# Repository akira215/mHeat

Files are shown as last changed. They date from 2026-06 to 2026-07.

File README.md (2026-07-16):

# mHeat
Monitoring HomeBus device and Modbus, embedded sofware on dedicated PCB using ESP32C6 µC

# Description

This repository contain all the development for an electronic device that will monitor a water tank (such as rain collect tank) using zigbee to transmit data to a coordinator. It contains: 
 * A PCB design [PCB design](PCB/README.md)
 * An enclosure design to be printed in 3D [Enclosure design](3Dprint/README.md)
 * Source code of the embedded software on the board (in an ESP32C6 µC)
 * An External converter for Zigbee2MQTT service [external converter](external_converters)

# Principle

The board will collect data from various sensors surch as:
 * Upstream static pressure (pump side)
 * Downstream static pressure (home side) - difference between upstream and downstream static pressure is used to estimate filters clogging
 * Water level sensor, to estimate the available water volume in the tank
 * water pulse meter to count the consumption in the home
 * Additionally on board temperature sensor could be monitor

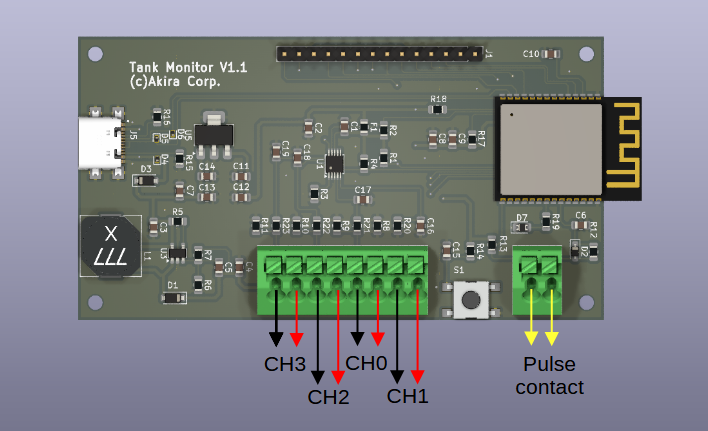
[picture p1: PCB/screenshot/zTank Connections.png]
zTank connections
 

 The 3 first sensors shall be 4-20mA sensor directly connected to the board. The water counter shall be a dry contact meter, connected to the board

 All these sensors have a calibration factor that can be updated directly form Zigbee2MQTT GUI. To avoid losing calibration, the device itself will keep updated theses factor in its Non Volatile Storage.

z2m settings (specific)

A 4-20mA input is available for any other futher sensor requirement. Adding a sensor will require to :
 * Update the embedded software
 * Update the external converter on Zigbee2MQTT side

## Usage

  * Short press button to join the zigbee network (coordinator shall grant pairing) -> LED shall flash, until network is joined, it then shutoff
  * Long press button to leave network. When the LED is fixed on, the device is not connected to the network neither is trying to join

## Sensor selection

### Upstream and downstream static pressure

  Regular pressure transmitter are not so expensive and efficient for that purpose. These 2 sensors shall have a measured range according to installation pressure. In regular network, pressure is limited to 3 bars, so selecting a sensor 0-5 bars seems a good choice. If the upper value is higher, the resolution of the measurement will be less as the ADC converter resolution is fixed.

  The shunt to convert current to tension for the ADC converter is 133R, and Imax for the sensor @max range will be 20mA so Umax for ADS1115 will be 2.66V (U=R*I). 5 bars = 500 kPa, so the calibration factor shall be 500 kPa / 2.66V = 187.97 kPa/V. Of course this factor shall be adjusted by measuring at the same location of one sensor the pressure, and correcting the reading of the sensor, but this short computation can help to start setting up calibration factor

### Water level

  Whatever technology of sensor could be used as soon as its output is 4-20mA current. Tests have been done using submerged differential pressure sensor, with the balance pipe to get the atmospheric pressure that run with the electrical cable, they worked properly. The range of this sensor shall be in accordance with the depth of the tank. The output value of Zigbee2MQTT will be a % of depth (meaning 100% when tank is full). Depending on the shape and cross section of the tank, this could be converted to a volume directly in the Z2M external converter, or outside Z2M in another software.

  The shunt to convert current to tension for the ADC converter is 133R, and Imax for the sensor @max range will be 20mA so Umax for ADS1115 will be 2.66V (U=R*I). For 100% the calibration factor shall be 100% / 2.66V = 37.594 %/V. 
  
  Of course this factor shall be adjusted when tank is full to read 100% in the Zigbee2MQTT output. For example, if yo have a 0-2m sensor and the require stroke of your tank (max height - min height before depriming pump) is 1.5m, it means that the 100% value of your tank will occur when sensor will read 1.5m (take care to install the sensor just before depriming pump). The voltage at the converter will be 1.5m/2m * 2.66V = 1.995V, so you will have to set the calibration factor considering 100% / 1.995V = 50.125%/V

### Water pulse counter

  The water meter shall send a pulse each XX L, whatever XX is. It is expected to have a dry contact that switch on and off each pulse. Hardware debouncer has been implemented for a particular counter, measuring bouncing using an oscilloscope. Computation of this RC filter has been provided here:
  [Spreadsheet](<PCB/2024-06-29 Comput.ods>)
    
  The kFactor to be set up in Zigbee2MQTT is only the L per pulse of the counter.

## Zigbee2MQTT integration

### External converter

External converter shall be loaded according to Zigbee2MQTT instructions:

[Zigbee2MQTT external converters](https://www.zigbee2mqtt.io/advanced/more/external_converters.html)

Restart Zigbee2MQTT `Webpage > Settings > Tools > Restart Zigbee2MQTT`

### Pairing zTank device

If the LED is fixed on, short press one time on the button, this will put the device in pairing mode.
Device is in Pairing Mode when the LED flahes quickly. 

Put Coordinator (or other device) in pairing mode using Zigbee2MQTT GUI (antenna symbol on the upper right of the screen with mention `All`)

After a short time, LED shall stop flashing. When LED is off, device is paired. You can check on Zigbee2MQTT device list

### Device icon

To add an icon in Zigbee2MQTT GUI, create a folder named `device_icon` in the root of Zigbee2MQTT docker installation (folder containing `configuration.yml`). In that foler, put the `zTank_icon.png` file contained in the `img` directory of this repository.

On Zigbee2MQTT GUI, go to `Devices` list and click on the device. Go to `Settings` tab and scroll down to the `icon` box.
Put `device_icons/zTank_icon.png` in that box. Icon shall be visible on Zigbee2MQTT GUI.

### Reporting

To develop*******************************************************************

## Build Instructions

The embedded software required `esp-ash-components`:

```
git submodule add https://github.com/akira215/esp-ash-components.git components
```

Create a partition.csv for zigbee and configure menuconfig with custom partition table (shall be done by default)

## Configuration

Configuration is available in `menuconfig` in the `Project setting` section:

### Pin Layout

  This section refer to hardware connection of LED button and volume meter. <span style="color:red">**These settings shall not be changed unless new hardware is developped.**</span>

pin layout

### Zigbee endpoints

  This section refer to the endpoint for each sensor of the device. Any change in this number require to update the external converter accordingly

Zigbee endpoints

  And in Zigbee2MQTT external converter:

External converter

### Zigbee device

  Zigbee stack has been sized doing extensive tests. <span style="color:red">**This setting shall not be changed.**</span>

Zigbee device

### ADS Pin Layout

  This section refer to hardware connection of ADS1115 converter to µC pin. <span style="color:red">**These settings shall not be changed unless new hardware is developped.**</span>

ADS pin layout

### ADS Converter config

  The first 3 inputs refer to the channel in which each sensor is connected. Take care that channel are not implemented on the connector in a logical order, so please refer to pictures that describe which pins of the connector is connected to which ADC channel (and polarity for sensors)

  The delay between 2 queries of ADS is the update rate of the measurement. Between 2 measurement, ADS is put in sleep to optimize consumption. Take care that driver will trigger one conversion for each channel, so there is a minimal time between 2 queries, depending on the resolution set for the ADS.

  The delay between 2 queries of temperature is the update rate of the measurement of the internal µC temperature sensor.

ADS converter config

## Current Status

Still work in progress, but is completely running. All bugs 
could be reported to try to improve it.

## PCB design

[PCB design](PCB/README.md)

## Enclosure design design

[Enclosure design](3Dprint/README.md)

## Caveats

### To be developped

OTA update

## Usage and Examples

## Changes

### New in version 0.0.0

## Credits

 * [Zigbee2MQTT](https://github.com/Koenkk/zigbee2mqtt)

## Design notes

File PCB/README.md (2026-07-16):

# zHeat PCB
A dedicated PCB using ESP32C6 µC as been designed to optimize reliability and costs.

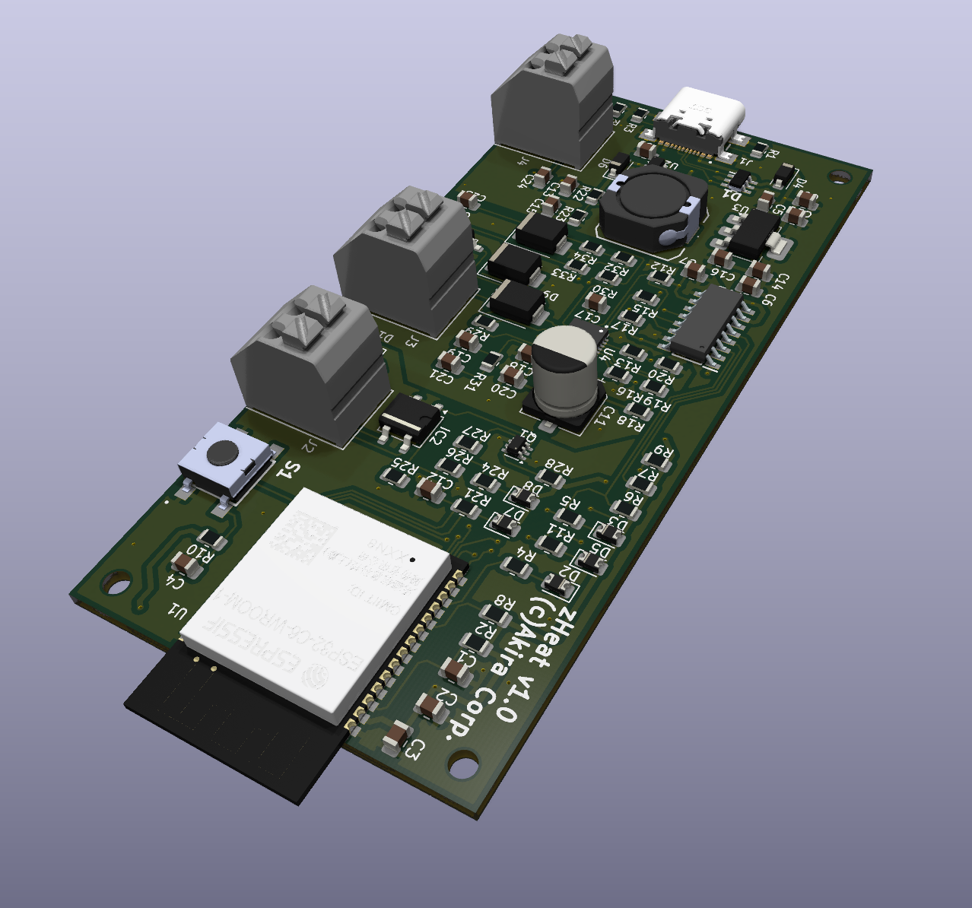
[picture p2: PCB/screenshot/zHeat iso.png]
Iso view of zTank PCB


The board connect to:

* Homebus to connect Daikin Heat Pump via P1P2 connector

* 12V serial bus to connect on heating circuit controller

* 4-20mA port to connect to pressure sensor on the circuit

## Tools

 The design of the PCB has been done with KiCad 10.0. Particular footprint and 3D STEP file are included in the `/library` folder for sake of maintenance

## Design

 The design is based on ESP32C6 WROOM with the following peripherials:
 * USB for power, flash device and output serial debug / info.
 * Powering circuit is done using MCP1826S 
 * A 4-20mA loop is built based on a LM2735X (1.6MHz) to raise voltage to about 20V
 * 4 channels 4-20mA sensors is provided and converted using ADS1115IDGS. It communicate with µC with i2c port
 * a debounced contact is provided for pulse counter
 * A push button is also provided for very simple HMI
 * PCB is also equipped by a LED for simpl HMI
 * Finally PCB is equipped with header that can be used for a touchscreen device in case of future needs (software lib already written and tested)

 Component size has been selected to 0805, except ESD protective diodes that are smaller.

### USB

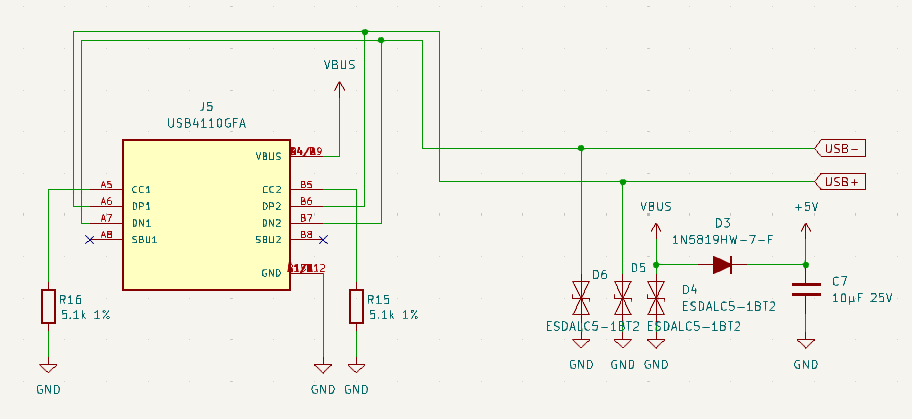
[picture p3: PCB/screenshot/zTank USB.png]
USB schematic
  

  USB socket is grounded to the main ground planes (2 sides).
  USB Lines `USB-` and `USB+` are directly connected to ESP32C6 to flash and monitor µC.
  `VBUS` is used to provide `+5V` (which is in fact lower than +5V) via a protective diode `D3`.

  All this 3 lines are protected by ESD protective diode.

### Voltage regulator

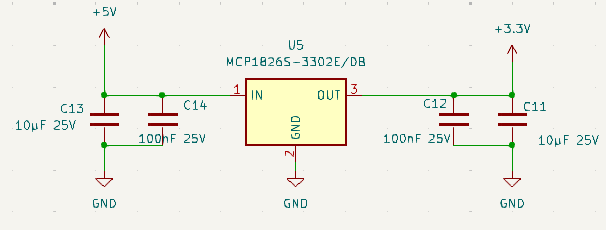
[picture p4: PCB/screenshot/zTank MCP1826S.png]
Regulator schematic
  

  All the board is powered using `+3.3V`. This voltage is provided by a fixed low-voltage regulator MCP1826S-3302E that can provide up to 1000mA.
  Fixed voltage regulator requires only few external component, in this case only capacitors are installed as per datasheet.

### 4-20mA Voltage circuit

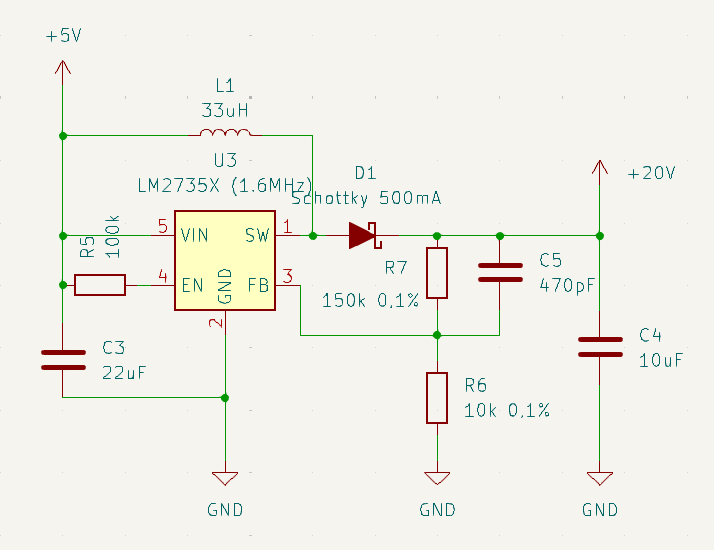
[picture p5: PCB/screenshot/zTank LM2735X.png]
LM2735X schematic
  

  To avoid noise on lines and due to voltage drop at each stage, 4-20mA loop voltage shall be at around 20V. Care shall be taken when changing this voltage as it may require adjustment (in the shunt values for instance) to avoid damaging other components.

  This voltage is produced from `+5V` using a boost type regulator LM2735X (@1.6MHz). Computation of the external components are provided in the LibreOffice Spreadsheet [PCB comput spreadsheet](<2024-06-29 Comput.ods>). A 33µH inductance has been selected to get a clean output voltage to avoid noise on sensors line.

### 4-20mA conversion

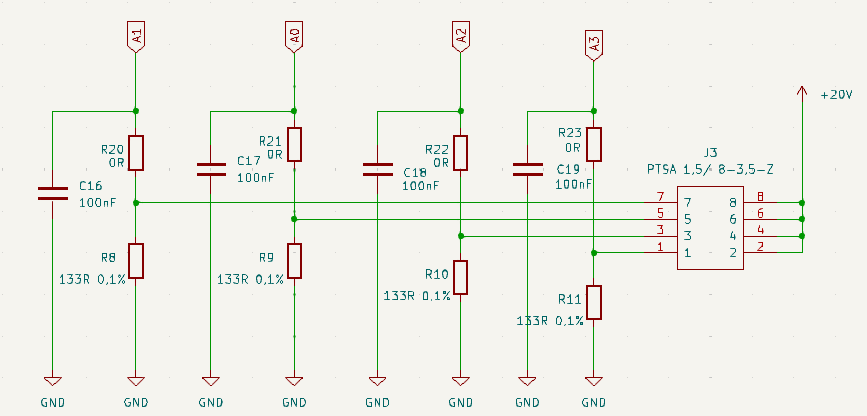
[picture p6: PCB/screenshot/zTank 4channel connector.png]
4 channel connector schematic
 

  4 channels are available via Phoenix contact 8 poles connector. Each channel input current is injected in a 133R shunt (low tolerance resistor) to output a voltage below 3.3V. A 100nF capacitor is provided to reduce noise.

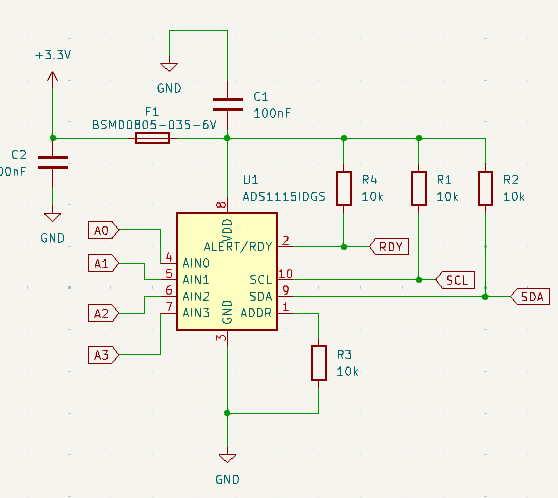
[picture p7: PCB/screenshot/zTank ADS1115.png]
ADS1115 schematic
  

  Each channel voltage is then converted in a digital signal using an ADS1115IDGS, that communicate with µC using i2c protocol. A ready pin is used to trigger an interrupt to the µC when data are available.
  External components are:
   * 10k resistor connected to the ground for the address of the device (only one on board so gnd is the common one)
   * 10k pull-up resistor on each signal (`SCL`, `SDA`, `RDY`) connected to µC
   * Decoupling capacitor for power lines and rearmable fuse to protect circuit

### Debounced contact

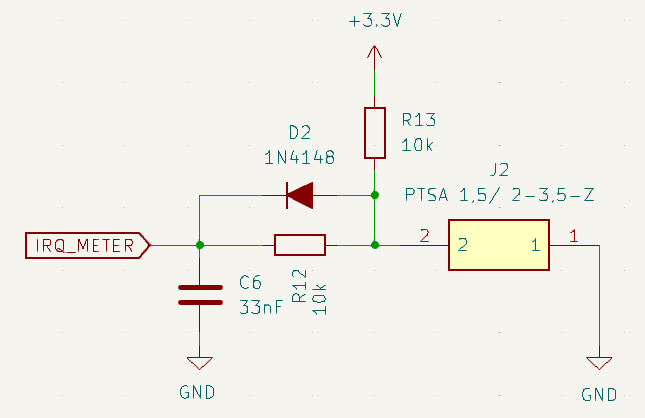
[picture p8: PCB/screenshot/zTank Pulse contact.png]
Debounced pulse schematic


An harware RC filter has been set up on this input to avoid false triggering. The computation of this filter is detailed in the spreadsheet file [PCB comput spreadsheet](<2024-06-29 Comput.ods>), bouncing duration has been measured using an oscilloscope in a unique water meter equiped with dry contact pulse output. It may be required to adjust this filter if the water meter seems to input false pulse to the µC. 

The only other component is a pull-up resistor to not let a float input.

### µC ESP32C6 WROOM

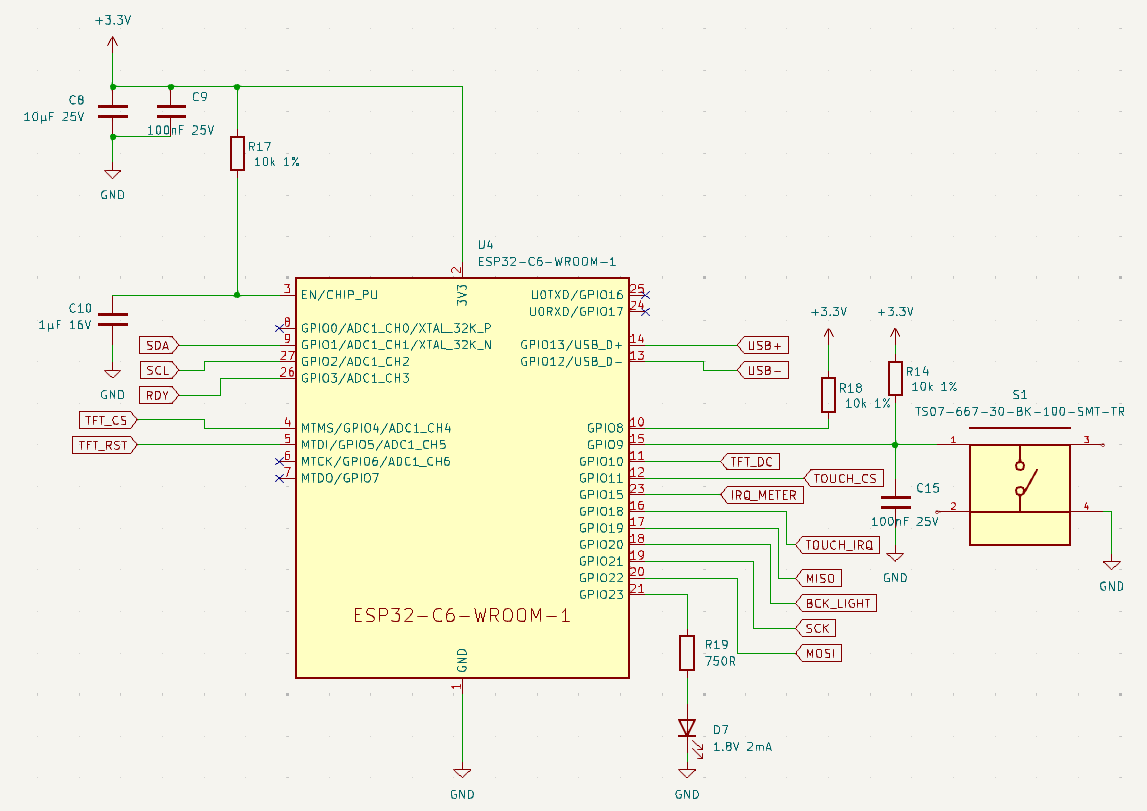
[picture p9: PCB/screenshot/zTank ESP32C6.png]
µC schematic


ESP32C6 power up is done using decoupling capacitor (10µF // 100nF).

The `EN` pin is driven to the `+3.3V` to enable the µC. 

`GPIO9` shall be pulled up to `+3.3V` to set the µC in normal execution mode (instead of ROM serial bootloader when `GPIO9` is pulled to the ground). Despite the doc says that it has an internal pull-up, µC will not boot normally after reporg if not driven to `+3.3V`.

`GPIO8` shall be driven to `+3.3V` as doc says, in order to enter the serial bootloader reliably.

### Push Button

Push button has been connected to `GPIO9`, so it can be used to boot/flash device by driving the pin low. Indeed, no operation is required on this button to flash µC using USB directly, and push button is used by software for HMI purpose.

### Led

A led is connected to `GPIO23` for HMI purpose as well. Resistor has been calculated according to LED spec to grant the required current.

### Header

A header is available to drive a touchscreen if required. It has not been integrated in the enclosure of this repo. It was planned and tested using a ILI9341 TFT touchscreen.

## PCB fabrication

Gerber files are included for fabrication. A batch of PCB has been produced by JLCPCB with the following configuration:

|Base Material |	FR-4	 | Layers |	2 |
|---|---|---|---|
|Dimension |	49 mm* 91 mm | PCB Qty |	20 |
|Product Type |	Industrial/Consumer electronics | Different Design |	1 |
|Delivery Format |	Single PCB	 | PCB Thickness |	1.6mm |
|Specify Stackup |	no	 | Layer Sequence | |	
|PCB Color |	Purple	 | Silkscreen |	White |
|Material Type |	TG135	 | Via Covering |	Tented |
|Surface Finish |	ENIG Gold Thickness: 1U"	 | Deburring/Edge rounding |	No |
|Outer Copper Weight  |	1 oz	 | Gold Fingers |	No |
|Electrical Test |	Flying Probe Fully Test	 | Castellated Holes |	no |
|Edge Plating |	No	 | Mark on PCB	 | Order Number |
|Blind Slot |	No	 | Min via hole size/diameter |	0.3mm/(0.4/0.45mm)|
|4-Wire Kelvin Test |	No	 | Paper between PCBs |	No |
|Appearance Quality |	IPC Class 2 Standard	 | Confirm Production file |	No |
|Silkscreen Technology|	Ink-jet/Screen Printing Silkscreen | Package Box |	With JLCPCB logo  |
|Inspection Report |	No	 | Board Outline Tolerance |	±0.2mm(Regular) |
|UL Marking |	No	 | Countersink Hole |	No |

## Assembly

A stencil as been produced by JLCPCB, so the assembly has been done using solder paste, manually placing components, and reflow is done using an hot plate.

The components that generate issues during that process are:
 * USB connector `J5` : often some bridges are created due to the high density of pin. It has to be manually fixed
 * ESD protection diodes `D4`, `D5` & `D6`: are they are really small and light, they moved during the reflow process. It has to be manually fixed with a soldering iron, as hot air gun make them move anyway whaterver the airflow is
 * Care should be taken on the pin of ADS converter `U1`(bridges) and µC `U4` (alke of solder)
 * Obviously connector `J1`, `J2` and `J3` have to be solded manually

## Usage

For routing simplicity, 4-20mA channels are not reparted logically on the board, please consider the scheme here below.

Debounced pulse contact don't have polarity.

Board connectors

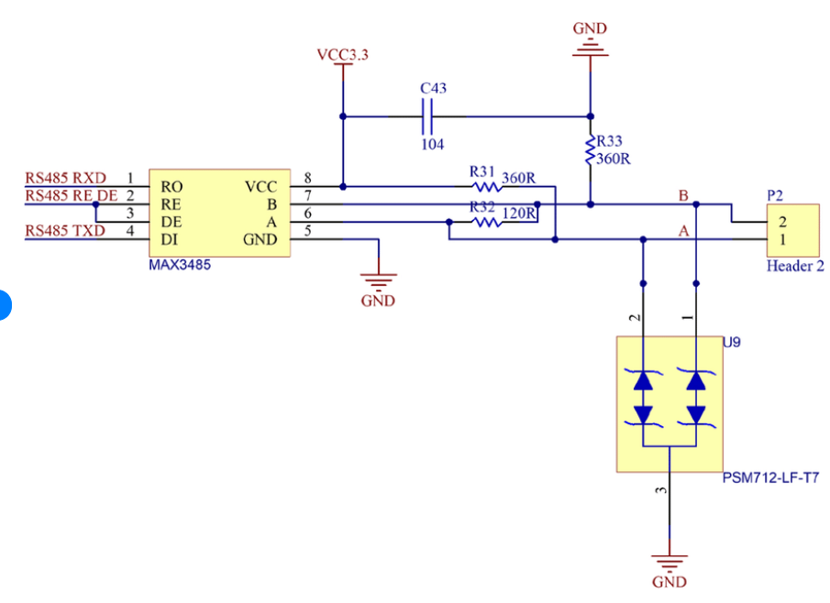
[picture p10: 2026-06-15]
00-Docs/MAX3485 schematic.png

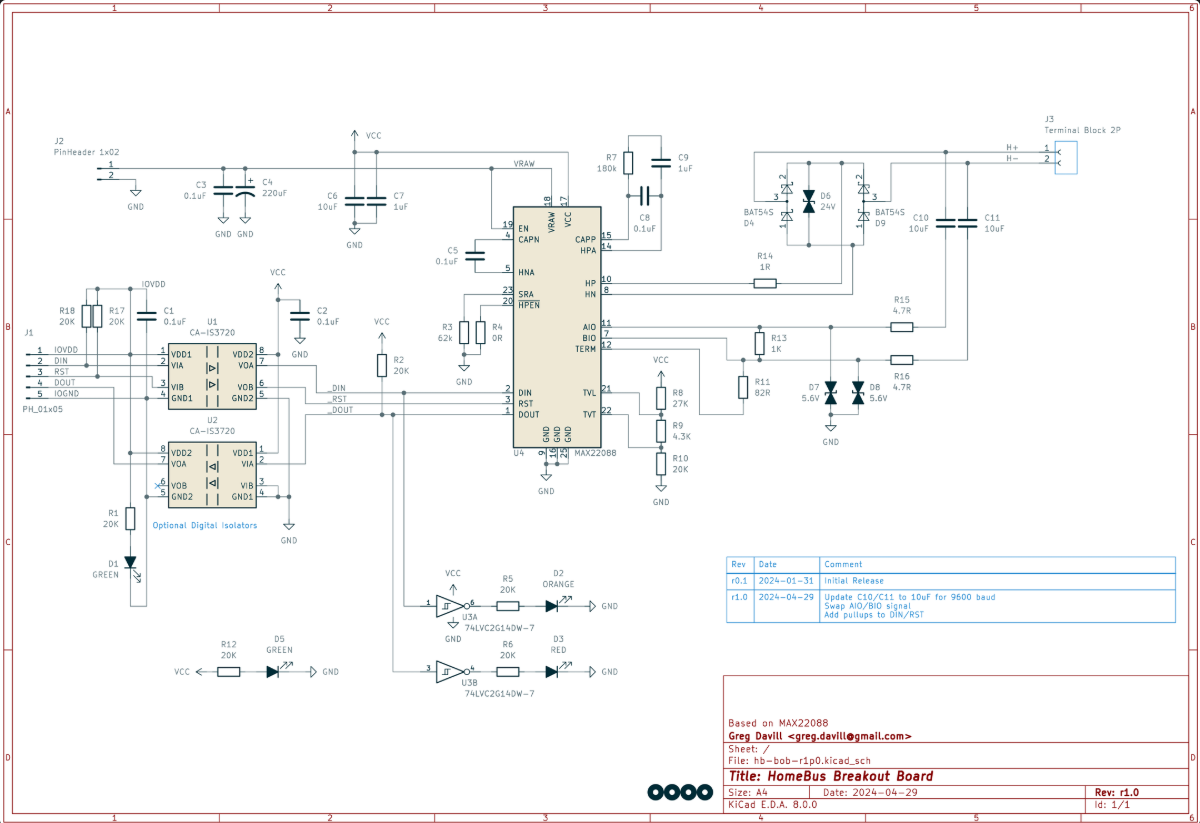
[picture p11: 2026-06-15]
00-Docs/Schematic P1P2.png

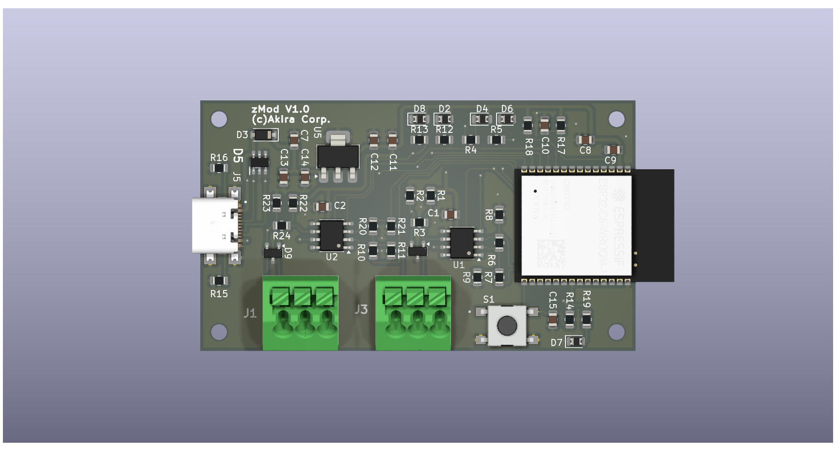
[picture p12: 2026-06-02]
PCB/screenshot/zVMC_PCB top.png

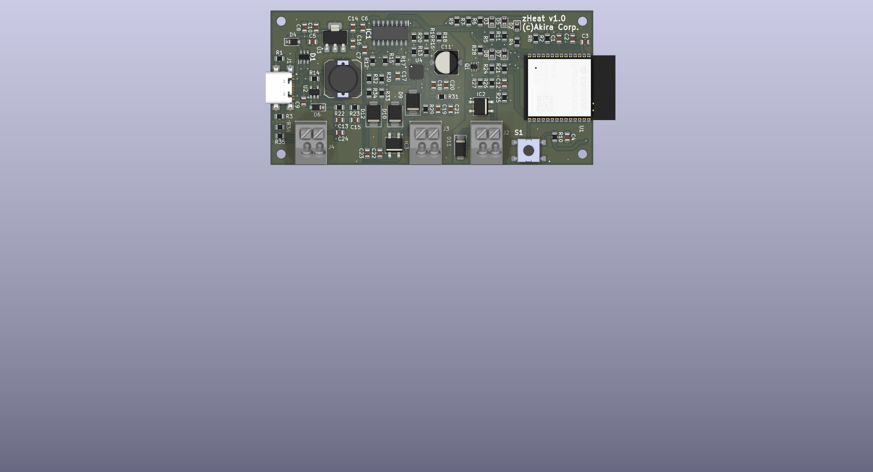
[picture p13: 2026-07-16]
PCB/screenshot/zHeat Connections.png

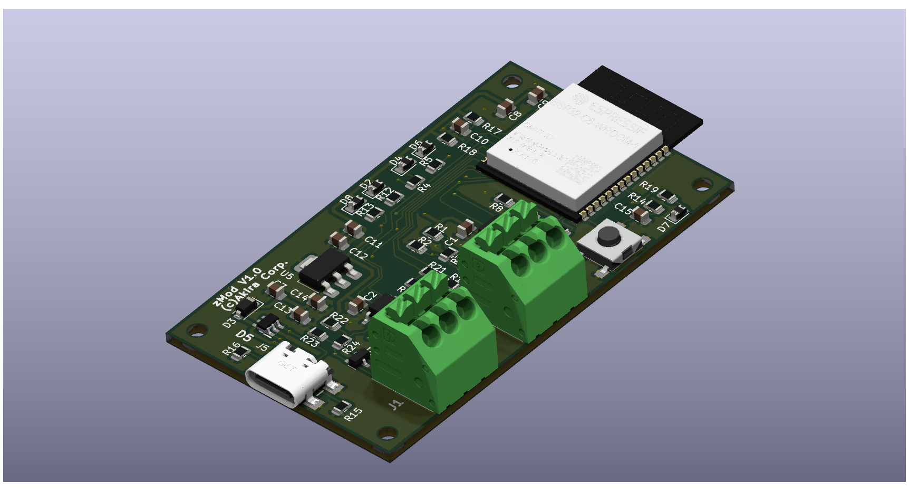
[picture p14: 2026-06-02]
PCB/screenshot/zVMC_PCB iso.png

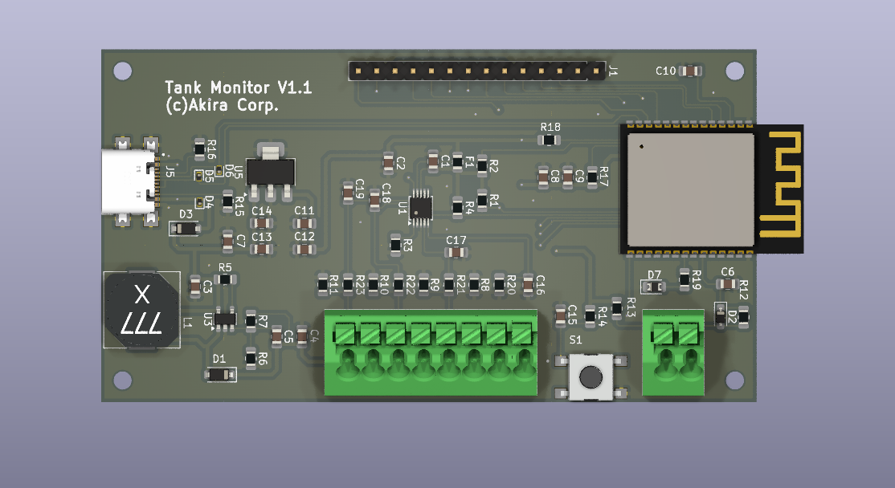
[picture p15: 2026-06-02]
PCB/screenshot/zTankV1_1 top-parall.png

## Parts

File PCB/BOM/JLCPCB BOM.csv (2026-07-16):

Designator | Comment | Footprint | LCSC | Assembly side | Assembly type | Assemble
R14 | YAGEO RC0805JR-07100KL | 805 | C100049 | top | SMT Assembly | Yes
D11 | MDD(Microdiode Semiconductor) SMAJ15CA | DO-214AC(SMA) | C110044 | top | SMT Assembly | Yes
R23 | YAGEO RT0805BRD0710KL | 805 | C110775 | top | SMT Assembly | Yes
R26 | YAGEO RC0805FR-073K9L | 805 | C114221 | top | SMT Assembly | Yes
R18 | YAGEO RC0805FR-0727KL | 805 | C114533 | top | SMT Assembly | Yes
R28 | YAGEO RC0805FR-075K6L | 805 | C114538 | top | SMT Assembly | Yes
R27 | YAGEO RC0805FR-076K8L | 805 | C114550 | top | SMT Assembly | Yes
R22 | YAGEO RT0805BRD07150KL | 805 | C136927 | top | SMT Assembly | Yes
R19 | YAGEO RC0805FR-074K3L | 805 | C137518 | top | SMT Assembly | Yes
R16 | YAGEO AC0805FR-070RL | 805 | C174076 | top | SMT Assembly | Yes
R10 | UNI-ROYAL 0805W8F1002T5E | 805 | C17414 | top | SMT Assembly | Yes
R12 | UNI-ROYAL 0805W8F1002T5E | 805 | C17414 | top | SMT Assembly | Yes
R15 | UNI-ROYAL 0805W8F1002T5E | 805 | C17414 | top | SMT Assembly | Yes
R17 | UNI-ROYAL 0805W8F1002T5E | 805 | C17414 | top | SMT Assembly | Yes
R2 | UNI-ROYAL 0805W8F1002T5E | 805 | C17414 | top | SMT Assembly | Yes
R35 | UNI-ROYAL 0805W8F1002T5E | 805 | C17414 | top | SMT Assembly | Yes
R6 | UNI-ROYAL 0805W8F1002T5E | 805 | C17414 | top | SMT Assembly | Yes
R7 | UNI-ROYAL 0805W8F1002T5E | 805 | C17414 | top | SMT Assembly | Yes
R8 | UNI-ROYAL 0805W8F1002T5E | 805 | C17414 | top | SMT Assembly | Yes
R9 | UNI-ROYAL 0805W8F1002T5E | 805 | C17414 | top | SMT Assembly | Yes
C13 | FH 0805B471K500NT | 805 | C1743 | top | SMT Assembly | Yes
R31 | UNI-ROYAL 0805W8F1803T5E | 805 | C17501 | top | SMT Assembly | Yes
R32 | UNI-ROYAL 0805W8F1001T5E | 805 | C17513 | top | SMT Assembly | Yes
R24 | UNI-ROYAL 0805W8F3300T5E | 805 | C17630 | top | SMT Assembly | Yes
R5 | UNI-ROYAL 0805W8F3300T5E | 805 | C17630 | top | SMT Assembly | Yes
R33 | UNI-ROYAL 0805W8F470KT5E | 805 | C17675 | top | SMT Assembly | Yes
R34 | UNI-ROYAL 0805W8F470KT5E | 805 | C17675 | top | SMT Assembly | Yes
R13 | UNI-ROYAL 0805W8F6202T5E | 805 | C17783 | top | SMT Assembly | Yes
R11 | UNI-ROYAL 0805W8F7500T5E | 805 | C17818 | top | SMT Assembly | Yes
R21 | UNI-ROYAL 0805W8F7500T5E | 805 | C17818 | top | SMT Assembly | Yes
R4 | UNI-ROYAL 0805W8F7500T5E | 805 | C17818 | top | SMT Assembly | Yes
R25 | UNI-ROYAL 0805W8F8201T5E | 805 | C17828 | top | SMT Assembly | Yes
R30 | UNI-ROYAL 0805W8F820JT5E | 805 | C17841 | top | SMT Assembly | Yes
C15 | Chinocera HGC0805R5106K500NSLJ | 805 | C22367830 | top | SMT Assembly | Yes
D9 | Littelfuse SMBJ24A | DO-214AA | C224017 | top | SMT Assembly | Yes
L1 | Sumida CDRH104RNP-330NC | SMD,10.2x10mm | C225051 | top | SMT Assembly | Yes
R29 | UNI-ROYAL 0805W8F100KT5E | 805 | C25271 | top | SMT Assembly | Yes
S1 | OMRON B3FS-1000P | SMD-4P,6.3x6mm | C271750 | top | SMT Assembly | Yes
D10 | UMW P6SMB6.8A | SMB | C2758562 | top | SMT Assembly | Yes
D12 | UMW P6SMB6.8A | SMB | C2758562 | top | SMT Assembly | Yes
J2 | WAGO 250-202 | ??,P=3.5mm(???) | C2765061 | top | Wave Soldering | Yes
J3 | WAGO 250-202 | ??,P=3.5mm(???) | C2765061 | top | Wave Soldering | Yes
J4 | WAGO 250-202 | ??,P=3.5mm(???) | C2765061 | top | Wave Soldering | Yes
R1 | UNI-ROYAL 0805W8F5101T5E | 805 | C27834 | top | SMT Assembly | Yes
R3 | UNI-ROYAL 0805W8F5101T5E | 805 | C27834 | top | SMT Assembly | Yes
C11 | KNSCHA RVT100UF25V67RV0011 | SMD,D6.3xL7.7mm | C2836443 | top | SMT Assembly | Yes
R36 | UNI-ROYAL TC0525B1200T5G | 805 | C2989047 | top | SMT Assembly | Yes
IC2 | Taiwan Semiconductor RMB6S | MBS | C3589251 | top | SMT Assembly | Yes
IC3 | Taiwan Semiconductor RMB6S | MBS | C3589251 | top | SMT Assembly | Yes
R20 | UNI-ROYAL 0805W8F2002T5E | 805 | C4328 | top | SMT Assembly | Yes
C9 | Samsung Electro-Mechanics CL21A226MAQNNNE | 805 | C45783 | top | SMT Assembly | Yes
J1 | Global Connector Technology USB4110-GF-A | SMD | C5143397 | top | SMT Assembly | Yes
C10 | YAGEO CC0805KRX7R8BB104 | 805 | C519981 | top | SMT Assembly | Yes
C12 | YAGEO CC0805KRX7R8BB104 | 805 | C519981 | top | SMT Assembly | Yes
C14 | YAGEO CC0805KRX7R8BB104 | 805 | C519981 | top | SMT Assembly | Yes
C17 | YAGEO CC0805KRX7R8BB104 | 805 | C519981 | top | SMT Assembly | Yes
C19 | YAGEO CC0805KRX7R8BB104 | 805 | C519981 | top | SMT Assembly | Yes
C24 | YAGEO CC0805KRX7R8BB104 | 805 | C519981 | top | SMT Assembly | Yes
C3 | YAGEO CC0805KRX7R8BB104 | 805 | C519981 | top | SMT Assembly | Yes
C4 | YAGEO CC0805KRX7R8BB104 | 805 | C519981 | top | SMT Assembly | Yes
C6 | YAGEO CC0805KRX7R8BB104 | 805 | C519981 | top | SMT Assembly | Yes
C7 | YAGEO CC0805KRX7R8BB104 | 805 | C519981 | top | SMT Assembly | Yes
U4 | MAXIM MAX22088GTG+ | TQFN-24(4x4) | C5258925 | top | SMT Assembly | Yes
D6 | FUXINSEMI PMEG3005EGWXF | SOD-123 | C52747980 | top | SMT Assembly | Yes
U1 | ESPRESSIF ESP32-C6-WROOM-1-N8 | SMD,25.5x18mm | C5366877 | top | SMT Assembly | Yes
D1 | Nexperia BZA408B,115 | SOT-457 | C550053 | top | SMT Assembly | Yes
U2 | TI LM2735XMFX/NOPB | SOT-23-5 | C555454 | top | SMT Assembly | Yes
D3 | Kingbright APT2012LZGCK | 805 | C5569446 | top | SMT Assembly | Yes
D8 | Kingbright APT2012LZGCK | 805 | C5569446 | top | SMT Assembly | Yes
D2 | Kingbright APT2012LSECK/J3-PRV | SMD,2x1.3mm | C5879380 | top | SMT Assembly | Yes
D5 | Kingbright APT2012LSYCK/J3-PRV | SMD,2x1.3mm | C5879382 | top | SMT Assembly | Yes
D7 | Kingbright APT2012LSYCK/J3-PRV | SMD,2x1.3mm | C5879382 | top | SMT Assembly | Yes
U3 | MICROCHIP MCP1826S-3302E/DB | SOT-223-3 | C638624 | top | SMT Assembly | Yes
C16 | FH 0805X106M250NT | 805 | C669099 | top | SMT Assembly | Yes
C2 | FH 0805X106M250NT | 805 | C669099 | top | SMT Assembly | Yes
C20 | FH 0805X106M250NT | 805 | C669099 | top | SMT Assembly | Yes
C22 | FH 0805X106M250NT | 805 | C669099 | top | SMT Assembly | Yes
C23 | FH 0805X106M250NT | 805 | C669099 | top | SMT Assembly | Yes
C5 | FH 0805X106M250NT | 805 | C669099 | top | SMT Assembly | Yes
C8 | FH 0805X106M250NT | 805 | C669099 | top | SMT Assembly | Yes
IC1 | MAXIM MAX14932AASE+ | SOIC-16 | C7451518 | top | SMT Assembly | Yes
D4 | DIODES 1N5819HW-7-F | SOD-123 | C82544 | top | SMT Assembly | Yes
Q1 | Nexperia BC847BS,115 | TSSOP-6(SOT-363) | C8653 | top | SMT Assembly | Yes
C18 | YAGEO CC0805KKX7R8BB105 | 805 | C91186 | top | SMT Assembly | Yes
C21 | YAGEO CC0805KKX7R8BB105 | 805 | C91186 | top | SMT Assembly | Yes
C1 | YAGEO CC0805KKX7R7BB105 | 805 | C94122 | top | SMT Assembly | Yes

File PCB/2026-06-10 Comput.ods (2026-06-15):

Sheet: Led
Resistor computation for LED
 | Power supply | Vf | 3,3 | V
 | Vf [V] | I [mA] | Ures [V] | R [Ω] | Ref | Link
LED Red | 1,8 | 2 | 1,5 | 750 | APT2012LSECK/J3-PRV | https://www.mouser.fr/ProductDetail/Kingbright/APT2012LSECK-J3-PRV?qs=6oMev5NRZMEkGJkKIsAalQ%3D%3D
LED Green | 2,65 | 2 | 0,65 | 325 | APT2012LZGCK | https://www.mouser.fr/ProductDetail/Kingbright/APT2012LZGCK?qs=6oMev5NRZMHOosFiXb%2F3qw%3D%3D
LED Yellow | 1,85 | 2 | 1,45 | 725 | APT2012LSYCK/J3-PRV | https://www.mouser.fr/ProductDetail/Kingbright/APT2012LSYCK-J3-PRV?qs=6oMev5NRZMGoWLCc4feqUg%3D%3D
LED Blue | 2,65 | 2 | 0,65 | 325 | APT2012LVBC/D | https://www.mouser.fr/ProductDetail/Kingbright/APT2012LVBC-D?qs=6oMev5NRZMGErJYT6KZLXg%3D%3D
LED Orange | 1,8 | 2 | 1,5 | 750 | APT2012LSECK/J4-PRV | https://www.mouser.fr/ProductDetail/Kingbright/APT2012LSECK-J4-PRV?qs=6oMev5NRZMH7xdB4zkudcw%3D%3D
 |  |  |  |  |  |  | OOPPPPPP¨TURTTHHJJKKL%MM%%%%%M¨%MLVJGLGUNUUPPGO PI./IH U?JJFV ? BNBNUTFTJTUJKGKG

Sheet: Bridge rectifier
 |  |  | GWD
Input | 12 | V | 12 | V
Bridge rectifier forward V /D | 1 | V | 0,5 | V
R to +Vcc | 8,2 | k | 6,8 | k
R to GND | 3,9 | k | 3,4 | k
Input MCU V | 3,22314049586777 | V | 3,66666666666667 | V

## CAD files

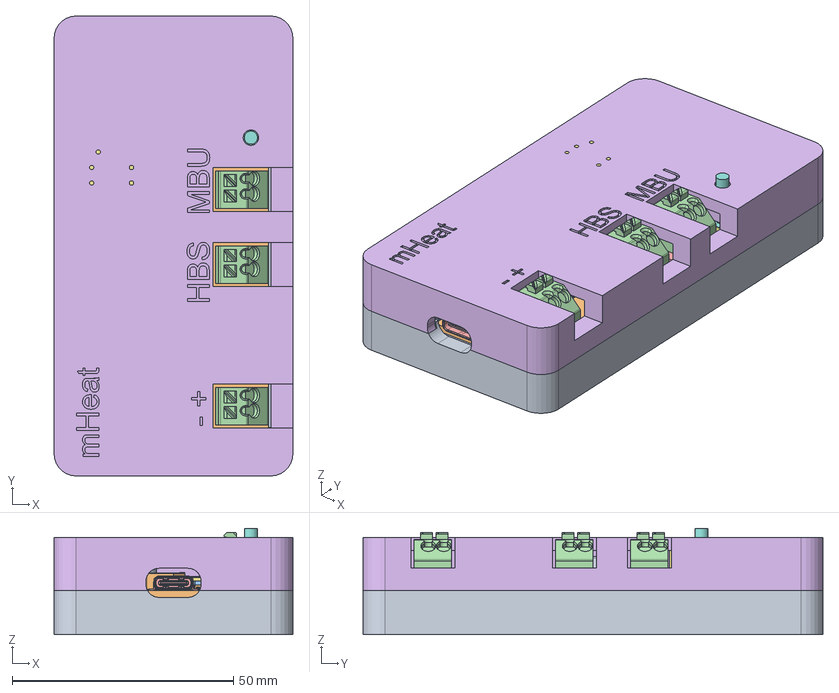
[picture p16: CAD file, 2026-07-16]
3Dprint/mHeat_enclosure.FCStd
54.0 x 104.0 x 24.0 mm
Enclosure_Bottom
Pcb_27ce
R21_R_0805_2012Metric_ef257e942385 x 36
C22_C_0805_2012Metric_1d7e8f8eb207 x 23
D3_D_0805_078918df5de8 x 5
IC3_TO-269AA_1c712c623c23 x 2
SOT457 Lower body001
SOT457 Lead006
SOT457 Lead007
SOT457 Lead008
SOT457 Lead009
SOT457 Lead010
SOT457 Lead011
SOT457 Upper body001
ESP32-C6-WROOM-1-N010
ESP32-C6-WROOM-1-N001
U2_SOT-23-5_8d38ed1f75a5
D6_D_SOD-123_a99bfd373765 x 2
D9_D_SMB_b0540b1f4b6f x 3
J3_250-202_301aeff188d3 x 3
B3FS-1000P
B3FS-1000P001
B3FS-1000P002
B3FS-1000P003
B3FS-1000P004
Q1_SOT-363_SC-70-6_34d1be4c6ddc
U3_SOT-223_d46927c9d4be
PinsArrayLR
PinsArrayLR001
PinsArrayLR002
PinsArrayLR003
PinsArrayLR004
PinsArrayLR005
PinsArrayLR006
PinsArrayLR007
PinsArrayLR008
PinsArrayLR009
PinsArrayLR010
PinsArrayLR011
PinsArrayLR012
PinsArrayLR013
PinsArrayLR014
PinsArrayLR015
USB4110-GF-A_revB(1) MF
Body_Solid1
Body001_Solid1
Array_Solid1
Array_Solid001
Array_Solid002
Array_Solid003
Array_Solid004
Array_Solid005
Array001_Solid2
Array001_Solid001
Array001_Solid002
Array001_Solid003
Array001_Solid004
Body002_Solid1
Array002_Solid1
Array002_Solid001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

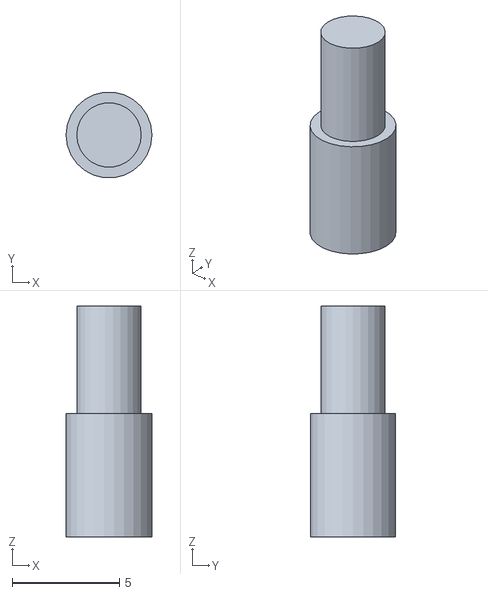
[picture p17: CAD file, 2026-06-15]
3Dprint/STL/zMod_enclosure-Button.stl
4.00 x 3.97 x 10.8

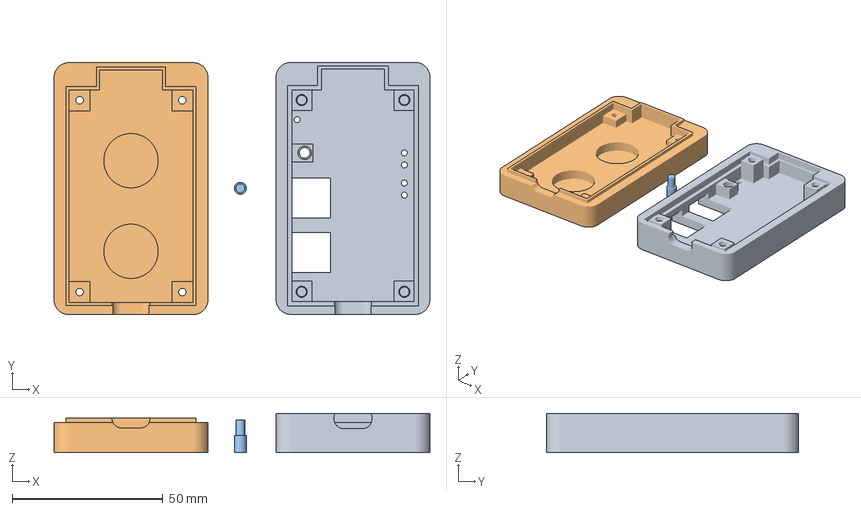
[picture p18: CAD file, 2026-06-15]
3Dprint/STL/zMod_enclosure-Enclosure_Top.3mf
124.5 x 83.6 x 13.0 mm
zMod_enclosure-Enclosure_Top.stl
zMod_enclosure-Enclosure_bottom.stl
zMod_enclosure-Button.stl

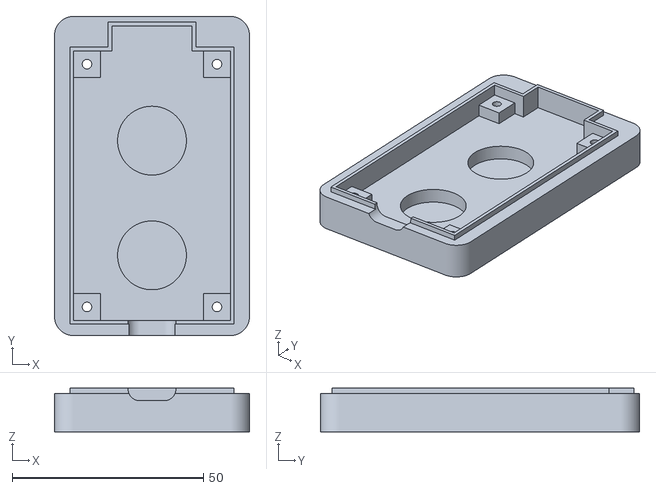
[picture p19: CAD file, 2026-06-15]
3Dprint/STL/zMod_enclosure-Enclosure_bottom.stl
51.0 x 83.5 x 11.5

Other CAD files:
3Dprint/STL/zMod_enclosure-Enclosure_Top.stl

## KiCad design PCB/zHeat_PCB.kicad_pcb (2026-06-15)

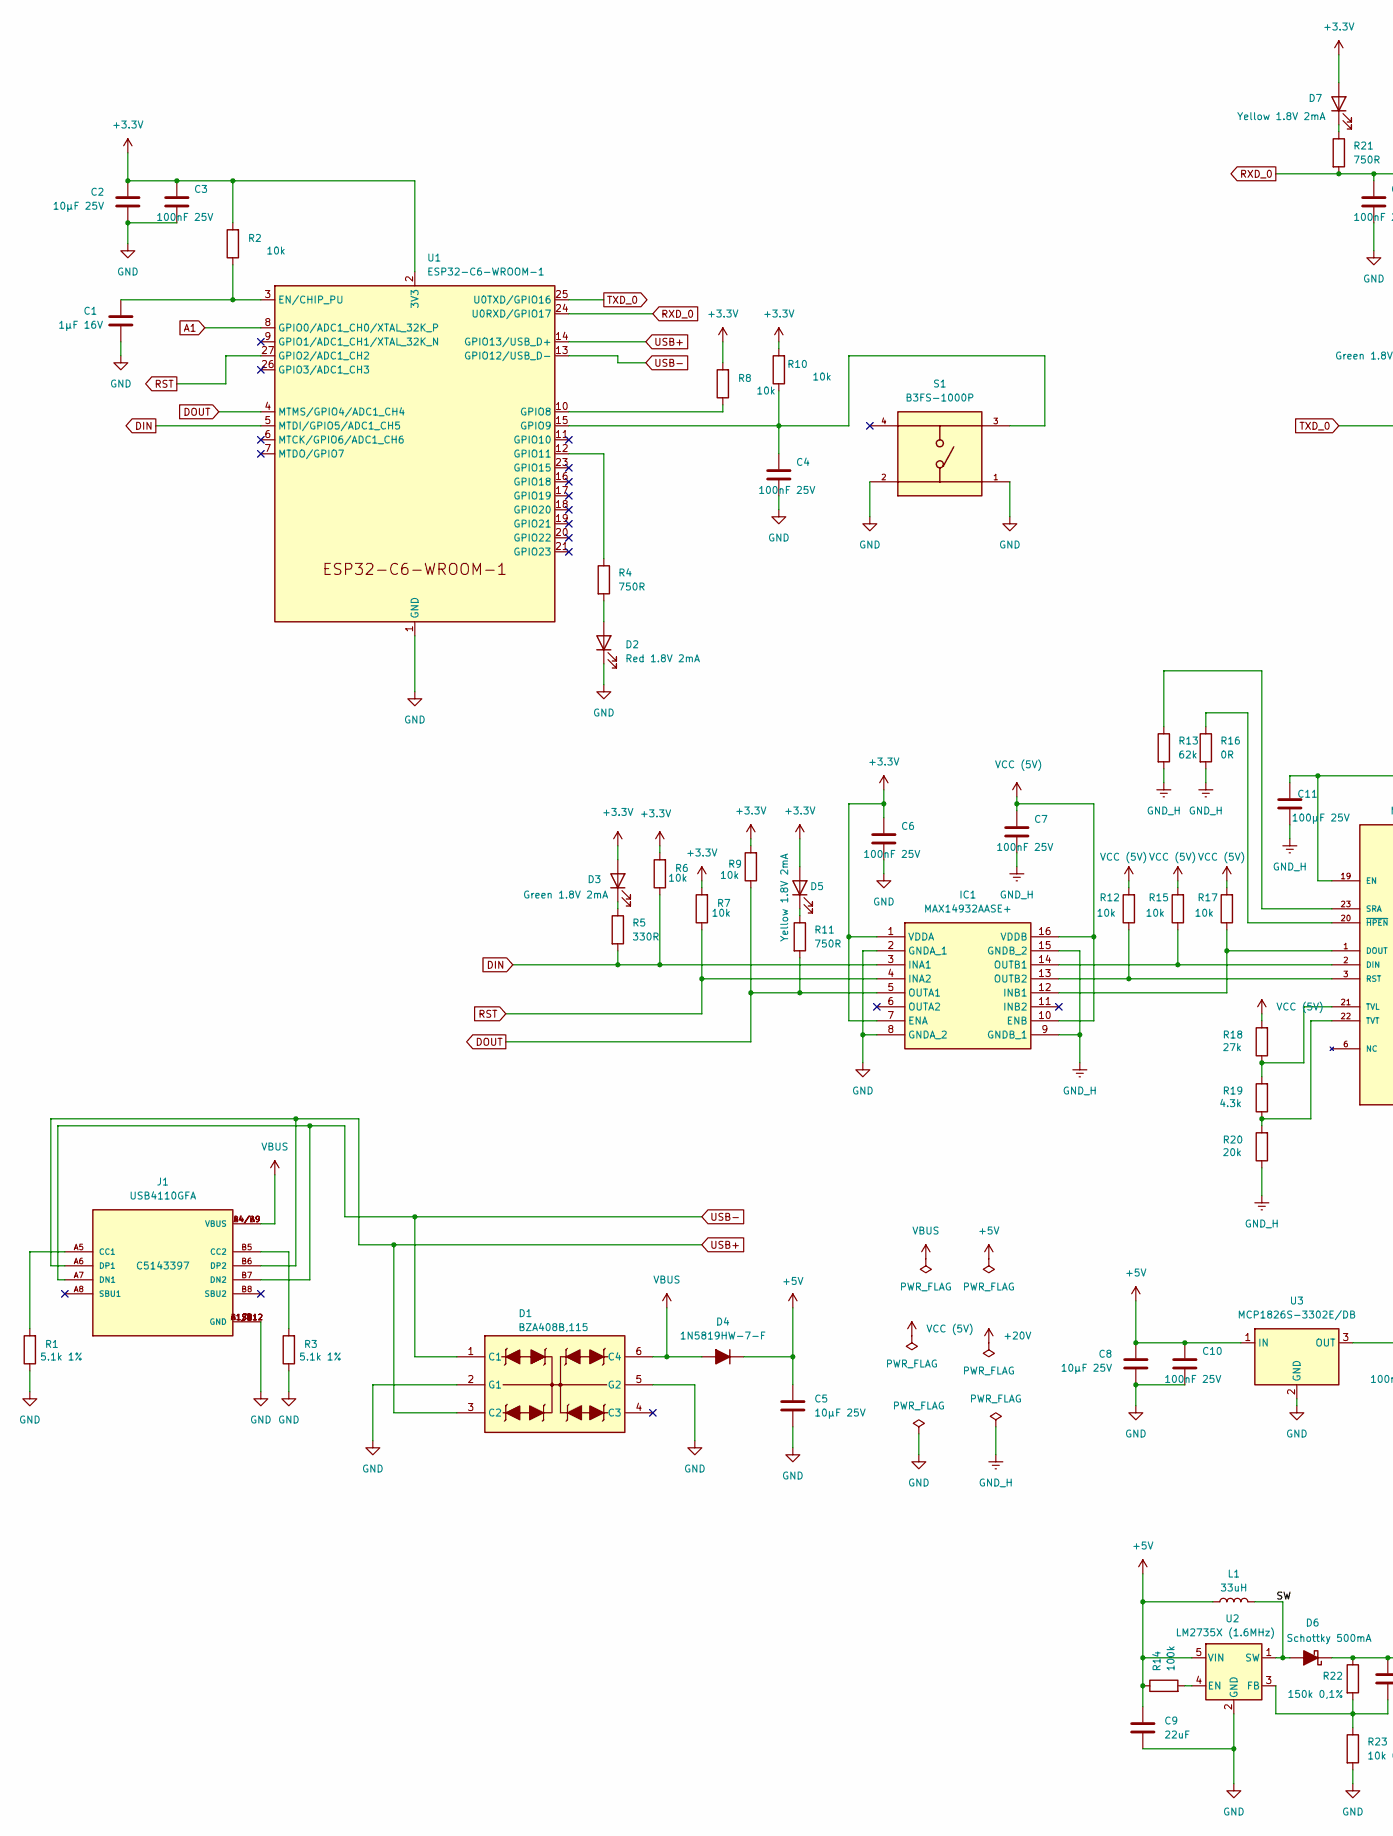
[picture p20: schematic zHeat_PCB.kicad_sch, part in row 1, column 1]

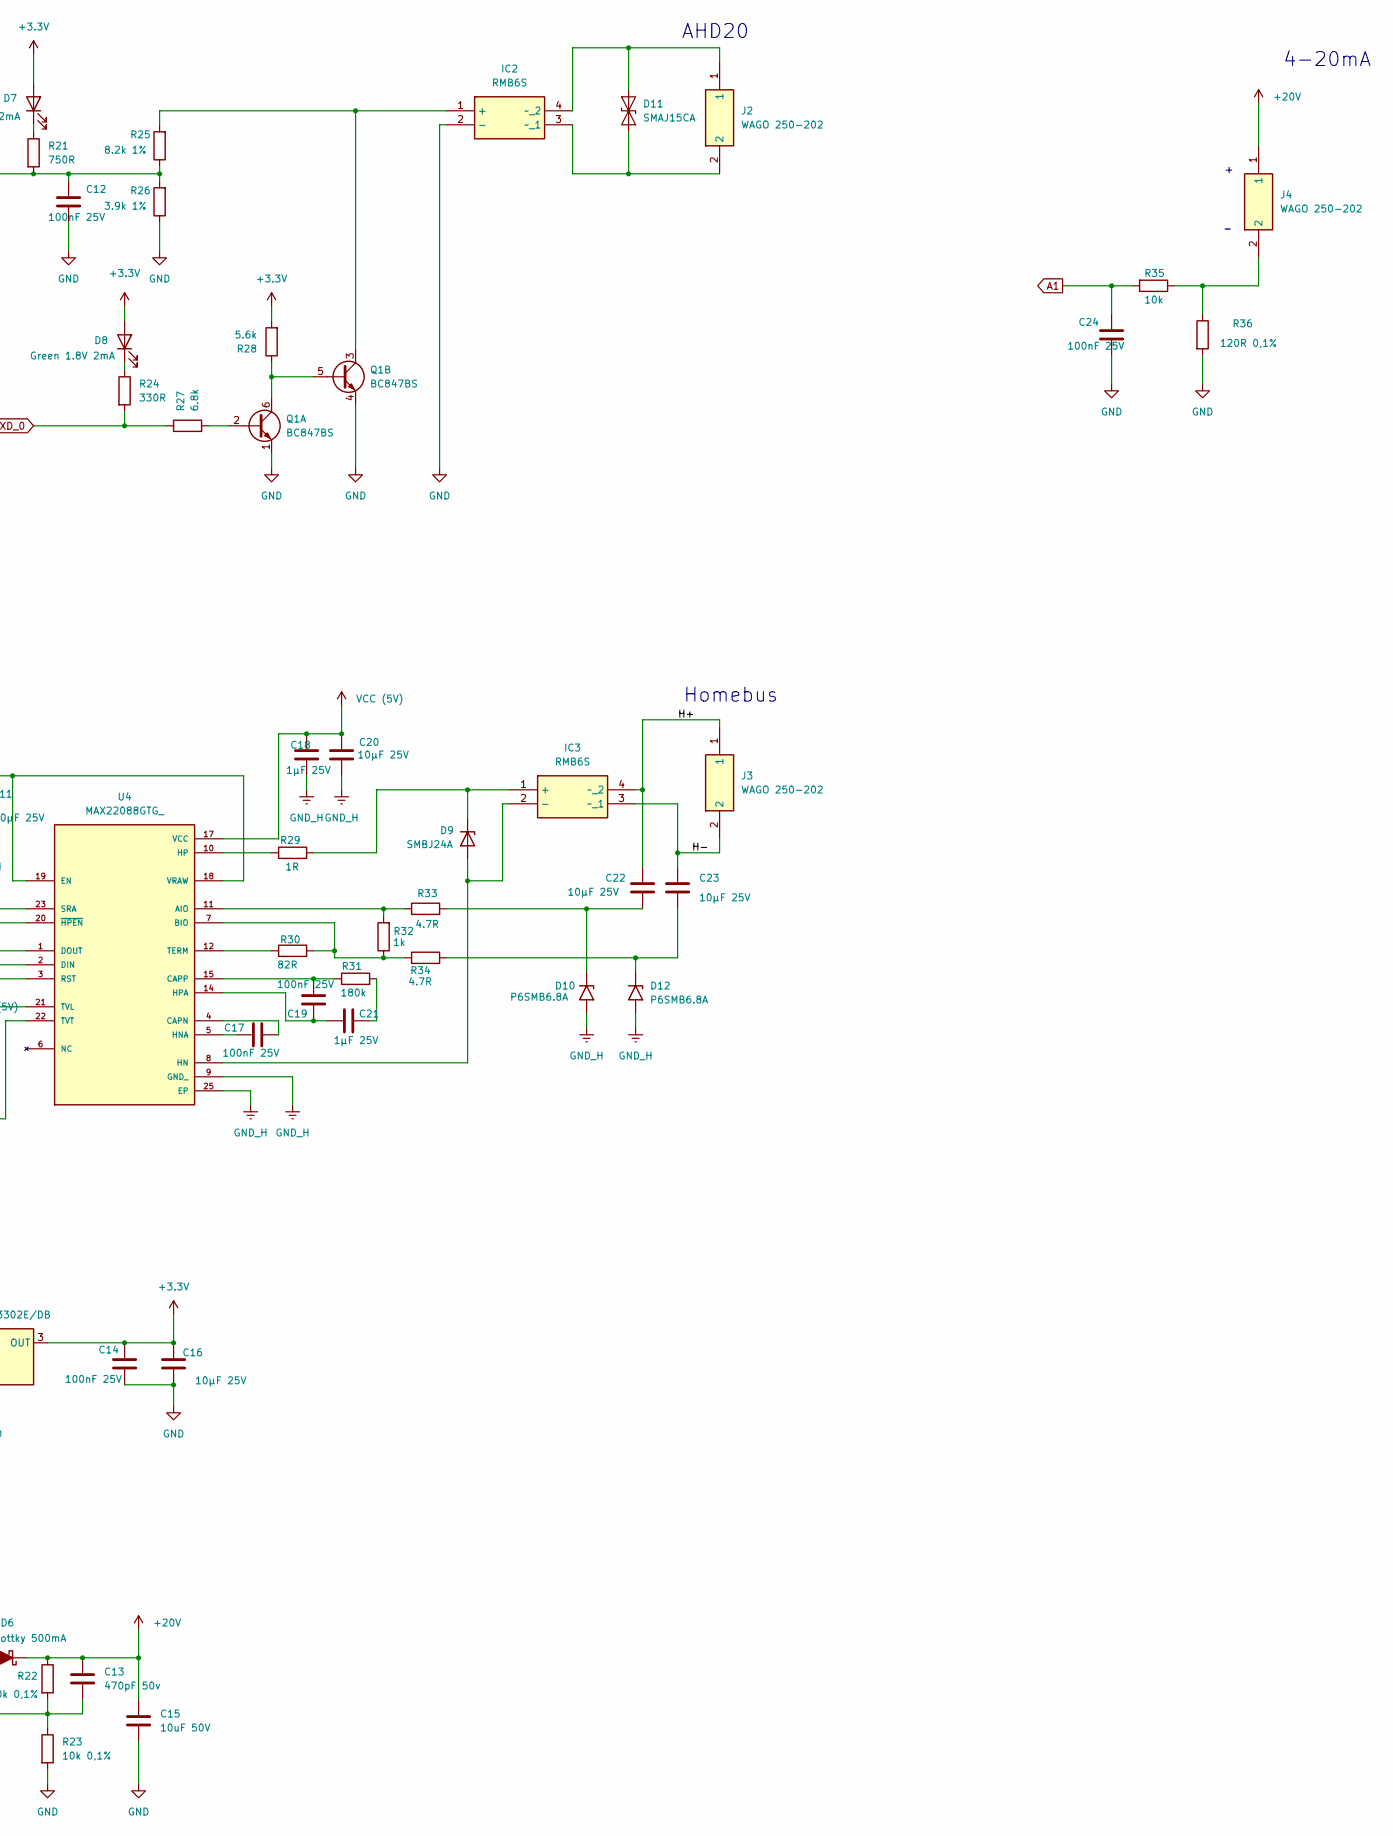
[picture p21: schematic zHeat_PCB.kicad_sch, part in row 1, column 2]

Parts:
C1: 1µF 16V; C_0805_2012Metric; LCSC C94122
C2, C5, C8, C16, C20, C22, C23: 10µF 25V; C_0805_2012Metric; LCSC C669099
C3, C4, C6, C7, C10, C12, C14, C17, C19, C24: 100nF 25V; C_0805_2012Metric; LCSC C519981
C9: 22uF; C_0805_2012Metric; LCSC C45783
C11: 100µF 25V; CP_Elec_6.3x7.7; LCSC C2836443
C13: 470pF 50v; C_0805_2012Metric; LCSC C1743
C15: 10uF 50V; C_0805_2012Metric; LCSC C22367830
C18, C21: 1µF 25V; C_0805_2012Metric; LCSC C91186
D1: BZA408B,115; SOT95P275X110-6N; Mouser Part Number 771-BZA408B,125
D2: Red 1.8V 2mA; D_0805_2012Metric; LCSC C5879380
D3, D8: Green 1.8V 2mA; D_0805_2012Metric; LCSC C5569446
D4: 1N5819HW-7-F; D_SOD-123; LCSC C82544
D5, D7: Yellow 1.8V 2mA; D_0805_2012Metric; LCSC C5879382
D6: Schottky 500mA; D_SOD-123; LCSC C52747980
D9: SMBJ24A; D_SMB; LCSC C224017
D10, D12: P6SMB6.8A; D_SMB; LCSC C2758562
D11: SMAJ15CA; D_SMA; LCSC C110044
IC1: MAX14932AASE+; SOIC127P600X175-16N; Mouser Part Number 700-MAX14932AASE+
IC2, IC3: RMB6S; TO-269AA; Mouser Part Number 512-MB1S
J1: USB4110GFA; GCT_USB4110GFA; LCSC C5143397
J2, J3, J4: WAGO 250-202; CONN2_250-202_WAG; Mouser Part Number 651-1985195
L1: 33uH; CDRH104RNP330NC; LCSC C225051
Q1: BC847BS; SOT-363_SC-70-6; LCSC C8653
R1, R3: 5.1k 1%; R_0805_2012Metric; LCSC C27834
R2, R6, R7, R8, R9, R10, R12, R15, R17, R35: 10k; R_0805_2012Metric; LCSC C17414
R4, R11, R21: 750R; R_0805_2012Metric; LCSC C17818
R5, R24: 330R; R_0805_2012Metric; LCSC C17630
R13: 62k; R_0805_2012Metric; LCSC C17783
R14: 100k; R_0805_2012Metric; LCSC C100049
R16: 0R; R_0805_2012Metric; LCSC C174076
R18: 27k; R_0805_2012Metric; LCSC C114533
R19: 4.3k; R_0805_2012Metric; LCSC C137518
R20: 20k; R_0805_2012Metric; LCSC C4328
R22: 150k 0,1%; R_0805_2012Metric; LCSC C136927
R23: 10k 0,1%; R_0805_2012Metric; LCSC C110775
R25: 8.2k 1%; R_0805_2012Metric; LCSC C17828
R26: 3.9k 1%; R_0805_2012Metric; LCSC C114221
R27: 6.8k; R_0805_2012Metric; LCSC C114550
R28: 5.6k; R_0805_2012Metric; LCSC C114538
R29: 1R; R_0805_2012Metric; LCSC C25271
R30: 82R; R_0805_2012Metric; LCSC C17841
R31: 180k; R_0805_2012Metric; LCSC C17501
R32: 1k; R_0805_2012Metric; LCSC C17513
R33, R34: 4.7R; R_0805_2012Metric; LCSC C17675
R36: 120R 0,1%; R_0805_2012Metric; LCSC C2989047
S1: B3FS-1000P; PARTREV 1.0; LCSC C271750
U1: ESP32-C6-WROOM-1; LCSC C5366877
U2: LM2735X (1.6MHz); SOT-23-5; LCSC C555454
U3: MCP1826S-3302E/DB; SOT-223-3_TabPin2; LCSC C638624
U4: MAX22088GTG_; QFN50P400X400X80-25N; PARTREV 4; LCSC C5258925

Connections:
+3.3V: C2.1, C3.1, C6.1, C14.1, C16.1, D3.2 (A), D5.2 (A), D7.2 (A), D8.2 (A), IC1.1 (VDDA), IC1.7 (ENA), R2.2, R6.2, R7.2, R8.2, R9.2, R10.2, R28.2, U1.2 (3V3), U3.3 (OUT)
+5V: C5.1, C8.1, C9.1, C10.1, D4.1 (K), L1.1, R14.1, U2.5 (VIN), U3.1 (IN)
+20V: C13.1, C15.1, D6.1 (K), J4.1, R22.1
/H+: C22.1, IC3.4 (~_2), J3.1
/H-: C23.1, IC3.3 (~_1), J3.2
/SW: D6.2 (A), L1.2, U2.1 (SW)
A1: C24.1, R35.2, U1.8 (GPIO0/ADC1_CH0/XTAL_32K_P)
DIN: IC1.3 (INA1), R5.2, R6.1, U1.5 (MTDI/GPIO5/ADC1_CH5)
DOUT: IC1.5 (OUTA1), R9.1, R11.2, U1.4 (MTMS/GPIO4/ADC1_CH4)
GND: C1.2, C2.2, C3.2, C4.2, C5.2, C6.2, C8.2, C9.2, C10.2, C12.2, C14.2, C15.2, C16.2, C24.2, D1.2 (G1), D1.5 (G2), D2.1 (K), IC1.2 (GNDA_1), IC1.8 (GNDA_2), IC2.2 (-), J1.A1/B12 (GND), J1.B1/A12 (GND), J1.S1 (GND), J1.S2 (GND), J1.S3 (GND), J1.S4 (GND), Q1.1 (E1), Q1.4 (E2), R1.1, R3.1, R23.2, R26.1, R36.2, S1.1, S1.2, U1.1 (GND), U1.28 (GND), U1.29 (GND), U2.2 (GND), U3.2 (GND)
GND_H: C7.2, C11.2, C18.2, C20.2, D10.2 (A2), D12.2 (A2), IC1.9 (GNDB_1), IC1.15 (GNDB_2), R13.2, R16.2, R20.1, U4.9 (GND_), U4.16 (GND_), U4.25 (EP)
unnamed: C21.1, R31.2
unnamed: D2.2 (A), R4.2
unnamed: D3.1 (K), R5.1
unnamed: D5.1 (K), R11.1
unnamed: D7.1 (K), R21.1
unnamed: D8.1 (K), R24.1
unnamed: D9.2 (A), IC3.2 (-), U4.8 (HN)
unnamed: D9.1 (K), IC3.1 (+), R29.2
unnamed: C22.2, D10.1 (A1), R33.2
unnamed: D11.1 (A1), IC2.3 (~_1), J2.2
unnamed: D11.2 (A2), IC2.4 (~_2), J2.1
unnamed: C23.2, D12.1 (A1), R34.2
unnamed: IC1.12 (INB1), R17.1, U4.1 (DOUT)
unnamed: IC1.14 (OUTB1), R15.1, U4.2 (DIN)
unnamed: IC1.13 (OUTB2), R12.1, U4.3 (RST)
unnamed: IC2.1 (+), Q1.3 (C2), R25.2
unnamed: J1.A5 (CC1), R1.2
unnamed: J1.B5 (CC2), R3.2
unnamed: J4.2, R35.1, R36.1
unnamed: Q1.2 (B1), R27.2
unnamed: Q1.5 (B2), Q1.6 (C1), R28.1
unnamed: C1.1, R2.1, U1.3 (EN/CHIP_PU)
unnamed: R8.1, U1.10 (GPIO8)
unnamed: C4.1, R10.1, S1.3, U1.15 (GPIO9)
unnamed: R4.1, U1.12 (GPIO11)
unnamed: R14.2, U2.4 (EN)
unnamed: C13.2, R22.2, R23.1, U2.3 (FB)
unnamed: R32.2, R33.1, U4.11 (AIO)
unnamed: R30.2, R32.1, R34.1, U4.7 (BIO)
unnamed: C17.2, U4.4 (CAPN)
unnamed: C19.2, R31.1, U4.15 (CAPP)
unnamed: C11.1, U4.18 (VRAW), U4.19 (EN)
unnamed: C17.1, U4.5 (HNA)
unnamed: R29.1, U4.10 (HP)
unnamed: C19.1, C21.2, U4.14 (HPA)
unnamed: R13.1, U4.23 (SRA)
unnamed: R30.1, U4.12 (TERM)
unnamed: R18.1, R19.2, U4.21 (TVL)
unnamed: R19.1, R20.2, U4.22 (TVT)
unnamed: R16.1, U4.20 (~HPEN)
RST: IC1.4 (INA2), R7.1, U1.27 (GPIO2/ADC1_CH2)
RXD_0: C12.1, R21.2, R25.1, R26.2, U1.24 (U0RXD/GPIO17)
TXD_0: R24.2, R27.1, U1.25 (U0TXD/GPIO16)
USB+: D1.3 (C2), J1.A6 (DP1), J1.B6 (DP2), U1.14 (GPIO13/USB_D+)
USB-: D1.1 (C1), J1.A7 (DN1), J1.B7 (DN2), U1.13 (GPIO12/USB_D-)
VBUS: D1.6 (C4), D4.2 (A), J1.A4/B9 (VBUS), J1.B4/A9 (VBUS)
VCC (5V): C7.1, C18.1, C20.1, IC1.10 (ENB), IC1.16 (VDDB), R12.2, R15.2, R17.2, R18.2, U4.17 (VCC)

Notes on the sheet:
AHD20
Homebus
4-20mA

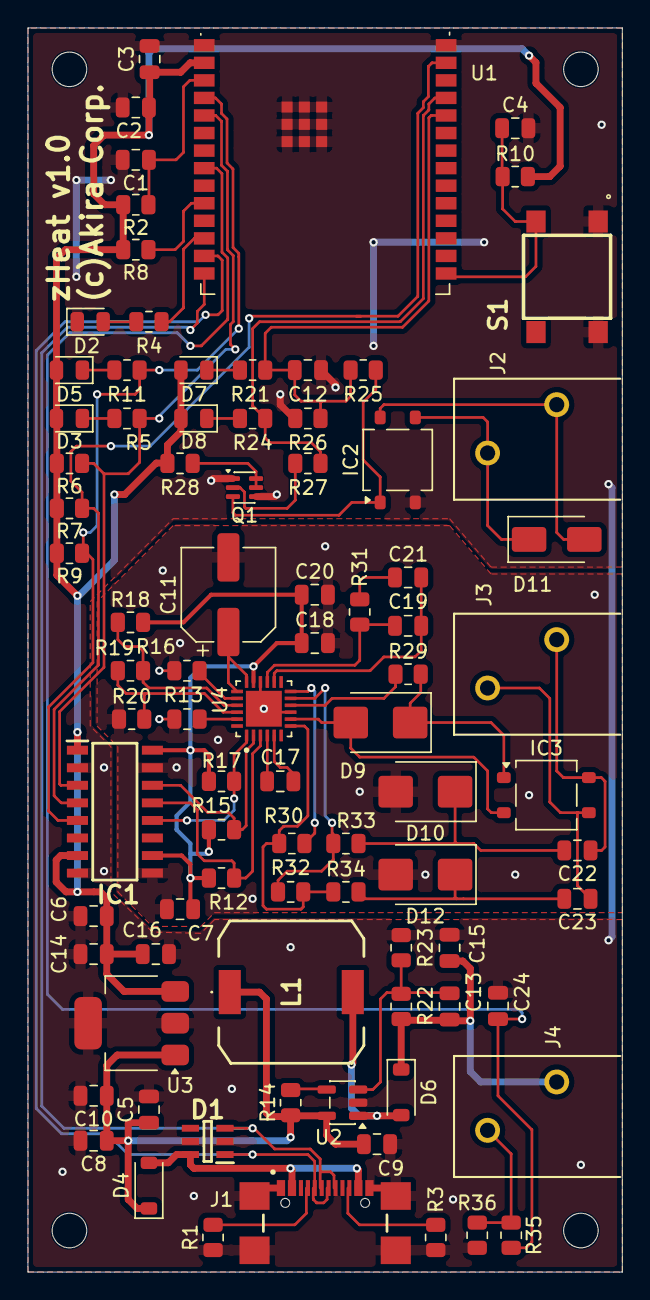
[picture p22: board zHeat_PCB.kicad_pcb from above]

Board: 2 copper layers, 43.0 x 90.0 mm, 86 parts (0 on the bottom side), 58 nets.

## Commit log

2026-06-02 project creation
    [2025-10-03 Comput.ods, zMod_PCB.csv, zMod_PCB.ods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]
2026-06-15 PCB for fabrication
    [2025-10-03 Comput.ods, 2026-06-10 Comput.ods, bom.csv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]
2026-07-16 PCB and Enclosure ready
    [JLCPCB BOM.csv, mHeat_enclosure.FCStd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]
